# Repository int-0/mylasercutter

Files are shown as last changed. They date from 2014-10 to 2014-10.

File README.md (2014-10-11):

# Mylasercutter project

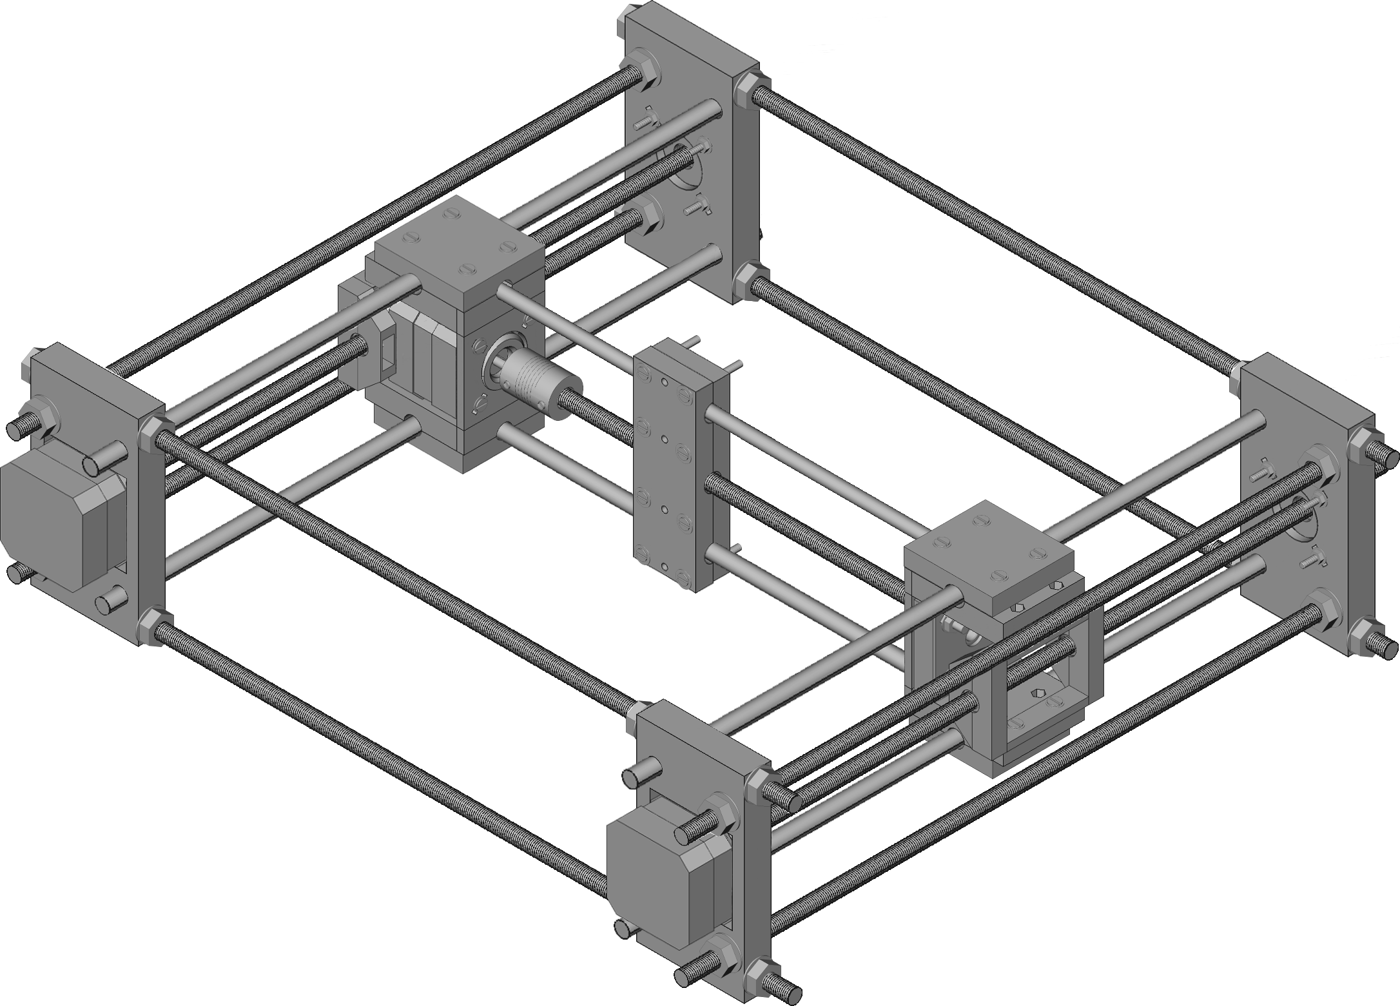
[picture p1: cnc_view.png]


This project is a CNC machine similar to reprap 3D printers. Hardware is
designed by me using FreeCAD and software is a fork of other existing
projects: [Sprinter](https://github.com/kliment/Sprinter) and [Pronterface](https://github.com/kliment/Printrun).

## How to build hardware

To make this CNC machine you need a 3D printer (or service) to print some
hardware parts. Other parts are rods, threaded rods, screws, nuts, linear
bearings. The most expensive hardware is all electronic stuff plus stepper
motors. You can buy some "Prusa kit" to get main board, Ramps and so on.
My prototype has been tested with XdrDuino (a 100% compatible Arduino board),
Ramps 1.4 and two stepper drivers.

Couplers have been made in aluminum but a plastic-printed couplers are valid
too.

For step-by-step manual you can check manual/ folder for more info.

## How to compile firmware

This Sprinter software can be made using Arduino IDE: just load Sprinter.ino
and click on "load" button. You can modify "Configuration.h" to setup CNC
sizes or if you need to tunning some parts like endstops, directions, and so on.

## How to check/run

You can test your CNC with Pronterface tool. Connect like a normal 3D printer
but uses only X/Y axis to move. Also you can send M52/M53 command to
enable/disable laser. This program cannot be used to print a gcode file because
it parses gcodes and fails with single-layer prints (or at least it doen't work
for me). In order to send gcode file in a "raw" mode, I write another
command-line tool in software/ folder based in Pronterface core. Just run:

```
$ ./send_cnc <gcode_file>
```

And that's all.

## Future work

The head of this CNC can be completed with some M3 nuts. This can be used
to design others tools like drills, etc. But firmware needs to be improvement
to allow Z movements.

## Known problems

Firmware fails with high feed rates (speed), so F>200 causes blocks
on stepper motors. Make sure that your gcodes don't have higher feed rates.

Please feel free to contribute and enjoy!

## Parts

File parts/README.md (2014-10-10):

# CND router printable parts

Hi,

All models are made with FreeCad. I'm not a expert user of any CAD program
so maybe parts can be done better. Please send me any improvements or
ideas.

## 3D Printing options

My prototype has been printing with PLA and using default options in Slic3r.
It works perfect and final structure is very solid and stable but feel free
to send your optimizations.

Thank you!

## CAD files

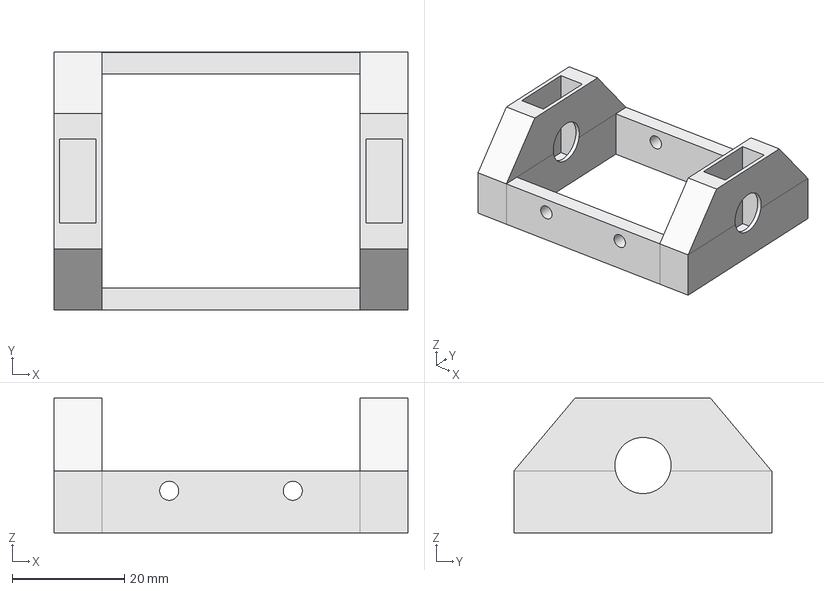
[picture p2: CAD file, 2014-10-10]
parts/freecad/y_carriage_fixation.fcstd
63.0 x 46.0 x 24.0 mm

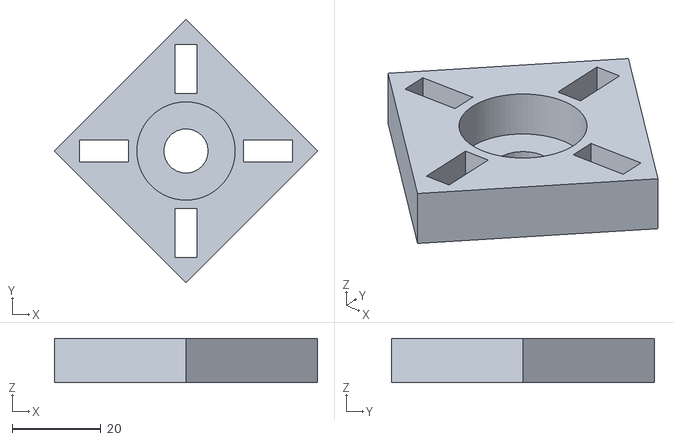
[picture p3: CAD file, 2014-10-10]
parts/stl/dummy_motot.stl
59.4 x 59.4 x 10.0

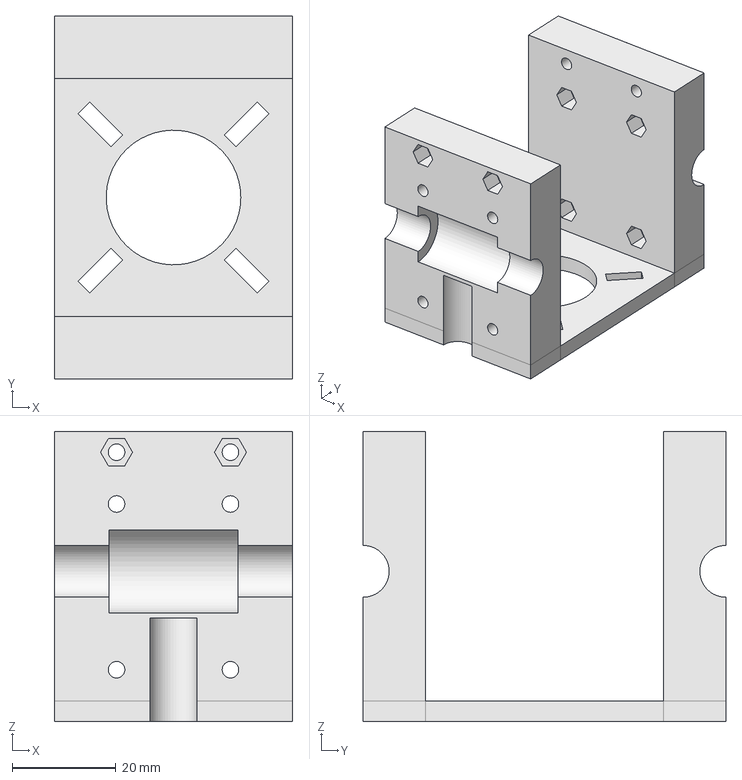
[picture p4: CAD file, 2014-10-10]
parts/freecad/y_carriage.fcstd
46.0 x 70.0 x 56.0 mm

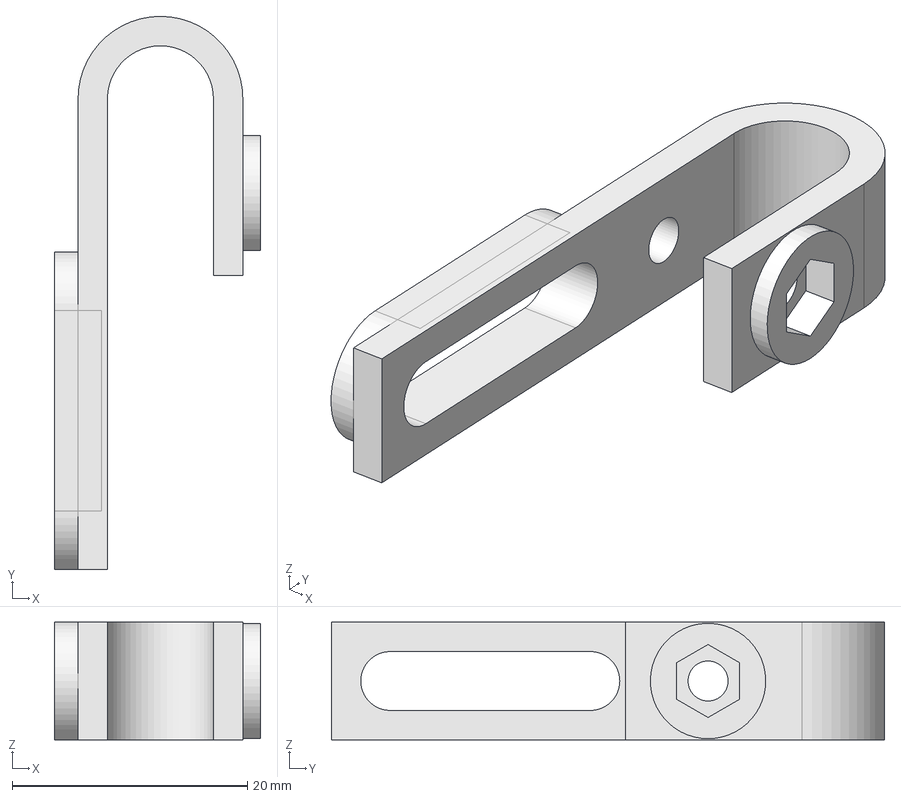
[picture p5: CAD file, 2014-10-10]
parts/freecad/rod_clamp.fcstd
17.5 x 47.0 x 10.0 mm

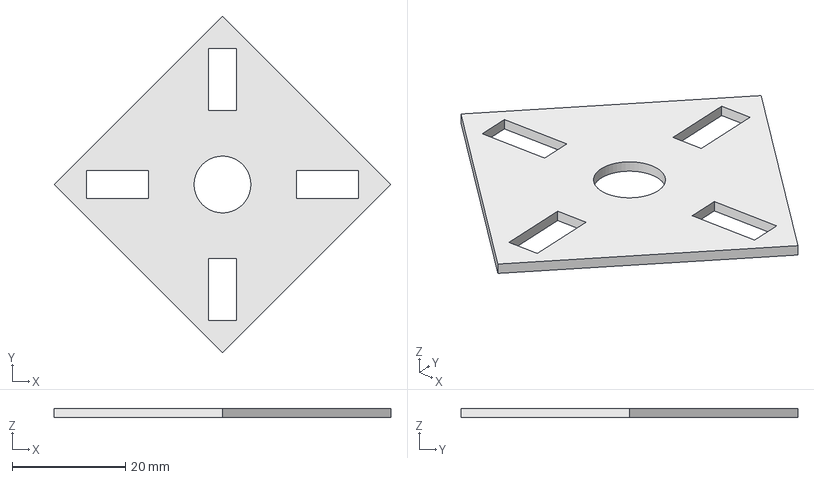
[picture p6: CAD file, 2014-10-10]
parts/freecad/dummy_motor_tap.fcstd
59.4 x 59.4 x 1.50 mm

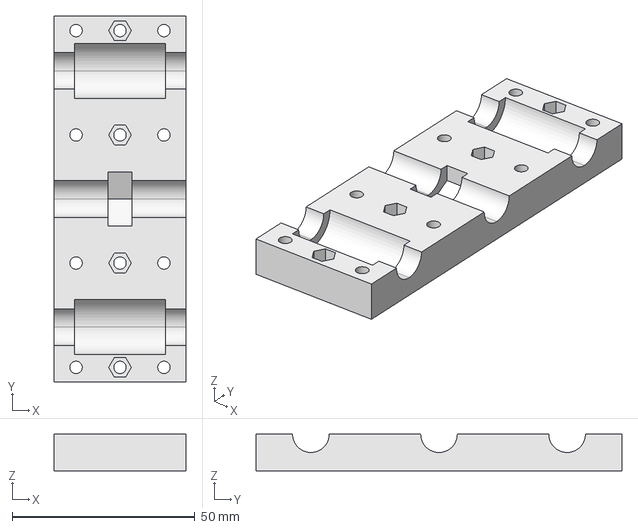
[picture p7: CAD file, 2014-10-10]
parts/freecad/x_carriage.fcstd
36.0 x 100.0 x 10.0 mm

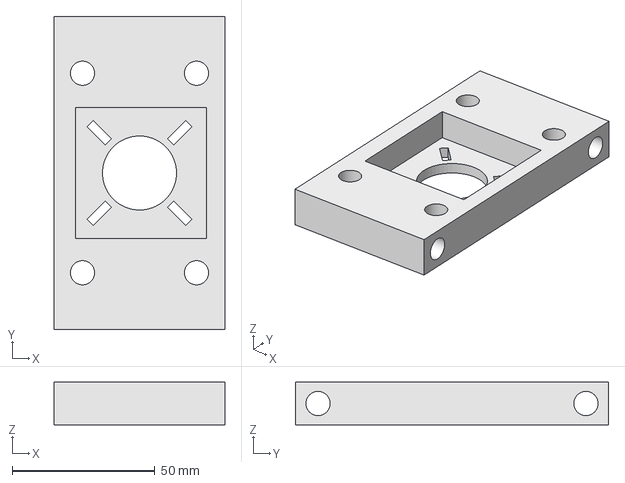
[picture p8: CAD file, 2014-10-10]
parts/freecad/frame_vertex.fcstd
60.0 x 110.0 x 15.0 mm

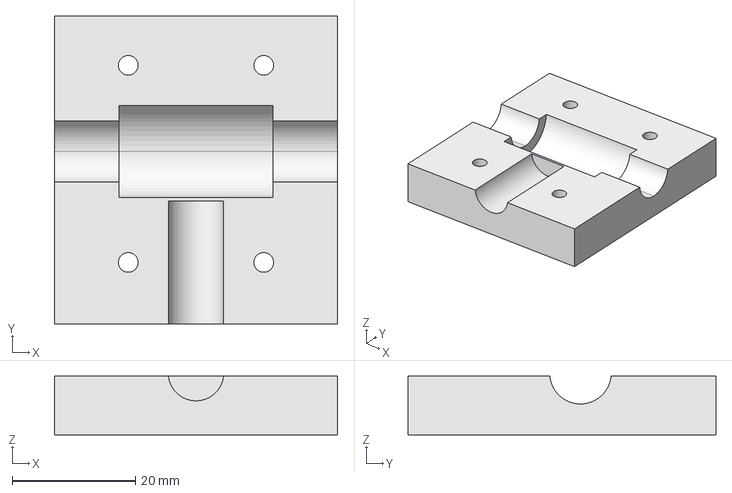
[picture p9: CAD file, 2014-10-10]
parts/freecad/y_carriage_tap.fcstd
46.0 x 50.0 x 9.50 mm

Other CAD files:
parts/freecad/dummy_motor.fcstd
parts/stl/dummy_motor_tap.stl
parts/stl/frame_vertex.stl
parts/stl/rod_clamp.stl
parts/stl/x_carriage.stl
parts/stl/y_carriage.stl
parts/stl/y_carriage_fixation.stl
parts/stl/y_carriage_tap.stl

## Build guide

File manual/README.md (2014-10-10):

# CNC router construction manual



Hi,

The following step-by-step manual is just for mounting the CNC router used
in my laser project. But this CNC router can be used to mount a common drilling
machine, but some modifications could be needed in the firmware.

NOTE: this manual does not include rods lenghts because sizes can be
      modified by user requeriments.

To compile this manual into one PDF file you can use this Makefile. Maybe you
need some extra packages:

```
# apt-get install librsvg2-bin pdftk
```

And then, just run make:

```
$ make
```

Enjoy!

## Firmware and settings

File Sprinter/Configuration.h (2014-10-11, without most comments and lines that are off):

#define CONFIGURATION_H
#define MOTHERBOARD 33
#define _AXIS_STEP_PER_UNIT {2560.0, 2560.0, 2560.0,990}
#define ENDSTOPPULLUPS // Comment this out (using // at the start of the line) to disable the endstop pullup resistors
const bool X_ENDSTOP_INVERT = true;
const bool Y_ENDSTOP_INVERT = true;
#define BAUDRATE 115200
#define USE_ARC_FUNCTION
#define X_ENABLE_ON 0
#define Y_ENABLE_ON 0
#define E_ENABLE_ON 0
const bool DISABLE_X = false;
const bool DISABLE_Y = false;
const bool DISABLE_E = false;
const bool INVERT_X_DIR = false;
const bool INVERT_Y_DIR = false;
const bool INVERT_E_DIR = true;
#define X_HOME_DIR -1
#define Y_HOME_DIR -1
const bool min_software_endstops = false; //If true, axis won't move to coordinates less than zero.
const bool max_software_endstops = true; //If true, axis won't move to coordinates greater than the defined lengths below.
const int X_MAX_LENGTH = 200;
const int Y_MAX_LENGTH = 200;
const int NUM_AXIS = 4; // The axis order in all axis related arrays is X, Y, Z, E
#define _MAX_FEEDRATE {6, 6, 6, 10}       // (mm/sec)
#define _HOMING_FEEDRATE {240, 240, 240}      // (mm/min) !!
#define _AXIS_RELATIVE_MODES {false, false, false, false}
#define MAX_STEP_FREQUENCY 30000 // Max step frequency
#define MAX_RETRACT_FEEDRATE 100    //mm/sec
#define _ACCELERATION 1000         // Axis Normal acceleration mm/s^2
#define _RETRACT_ACCELERATION 2000 // Extruder Normal acceleration mm/s^2
#define _MAX_XY_JERK 0.4
#define _MAX_E_JERK 4.0    // (mm/sec)
#define _MAX_ACCELERATION_UNITS_PER_SQ_SECOND {50.0, 50.0, 0.0, 0.0}    // X, Y, Z and E max acceleration in mm/s^2 for printing moves or retracts
#define MINIMUM_PLANNER_SPEED 0.05 // (mm/sec)
#define DEFAULT_MINIMUMFEEDRATE       0.0     // minimum feedrate
#define DEFAULT_MINTRAVELFEEDRATE     0.0
#define _MIN_SEG_TIME 20000
#define SLOWDOWN
const int dropsegments=5; //everything with less than this number of steps will be ignored as move and joined with the next movement
#define _DEF_CHAR_UUID "00000000-0000-0000-0000-000000000000"
#define BLOCK_BUFFER_SIZE 16
#define BLOCK_BUFFER_MASK 0x0f
#define MM_PER_ARC_SEGMENT 1
#define N_ARC_CORRECTION 25

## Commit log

2014-10-10 Adding CNC mounting manual
2014-10-10 Adding 3D printable models.
    [dummy_motor.fcstd, dummy_motor_tap.fcstd, dummy_motor_tap.stl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]
2014-10-10 Adding wiring schema.
2014-10-11 Program to send gcode files to lasercutter
2014-10-11 Adding Sprinter version for laser cutter
    [Configuration.h]
